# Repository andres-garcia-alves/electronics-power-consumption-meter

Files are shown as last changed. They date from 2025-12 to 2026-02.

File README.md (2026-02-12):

# Power Consumption Meter

A power consumption meter based on Arduino Nano.  
This project is a **work-in-progress**.

Two PCB versions are provided:
- Version A - With Battery Holder
- Version B - Without Battery Holder

&nbsp;

This project use the following electronic components:
- 01 x Double sided copper clad board (9x10cms)
- 01 x Arduino UNO / 01 x Arduino Nano v3
- 01 x Arduino socket (optional, 2x15)
- 01 x INA219 module
- 01 x INA219 socket (optional, 1x6)
- 01 x Display 5641BS, 7-segment, 4 digit, common anode
- 01 x Display socket (optional, 2x6)
- 11 x 470 ohm resistors
- 03 x LED diodes
- 01 x Rocker Button (optional, power on/off) / 01 x Jumper
- 01 x Switch Slide Button (power source selector)
- 01 x Switch Push Button (measure selector)
- 01 x 18650 (x2) batery holder / 01 x 9V Batery holder
- 01 x DC-jack connector (optional, externar power 5-12V)
- 01 x USB Type-A connector pair (male/female)
- 01 x USB Type-B Mini connector pair (male/female)
- 01 x USB Type-B Micro connector pair (male/female)
- 02 x DC connector-pair (male/female)
- 01 x Bornier 4-pin / 01 x JST conector 4-pin
- 04 x Bornier 2-pin / 02 x JST conector 2-pin

How to use:
- Conect this gadget between the device to measure and its power source.
- Pressing the push-button changes the measure tu display: voltage (V), consumption (mA), or total power (mW).

Features:
- Power input: 7-12V
- Measurements: 0-26V @3.2A (max)
- Accuracy: 0.01V, ~1mA, ~1mW

Notes:
- Measure only one device at a time, all power connectors intenally uses a common bus.
- Internal connections:
  - USB-A: power + data
  - USB-B mini/micro: power-only
  - DC-Jacks: power-only

&nbsp;

### Screenshots

| Breadboard | Assembly |
|---|---|
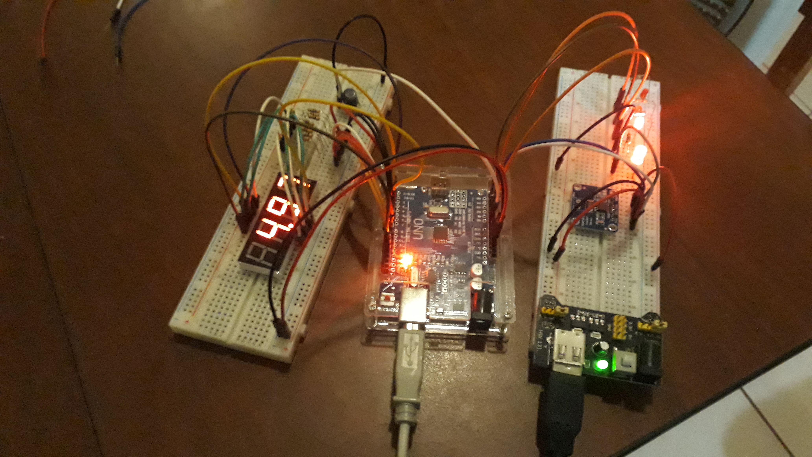
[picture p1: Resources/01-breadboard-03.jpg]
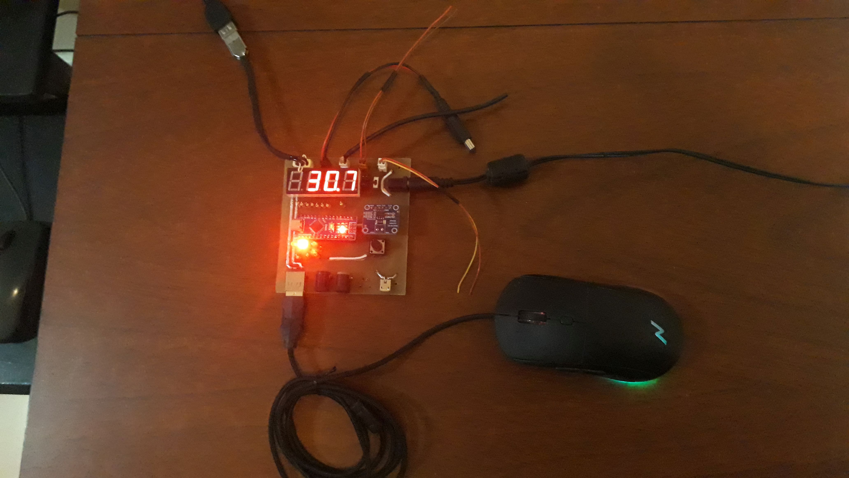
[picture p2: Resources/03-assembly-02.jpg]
|  |  |

| Version A - Schematics Diagram | Version A - PCB Diagram |
|---|---|
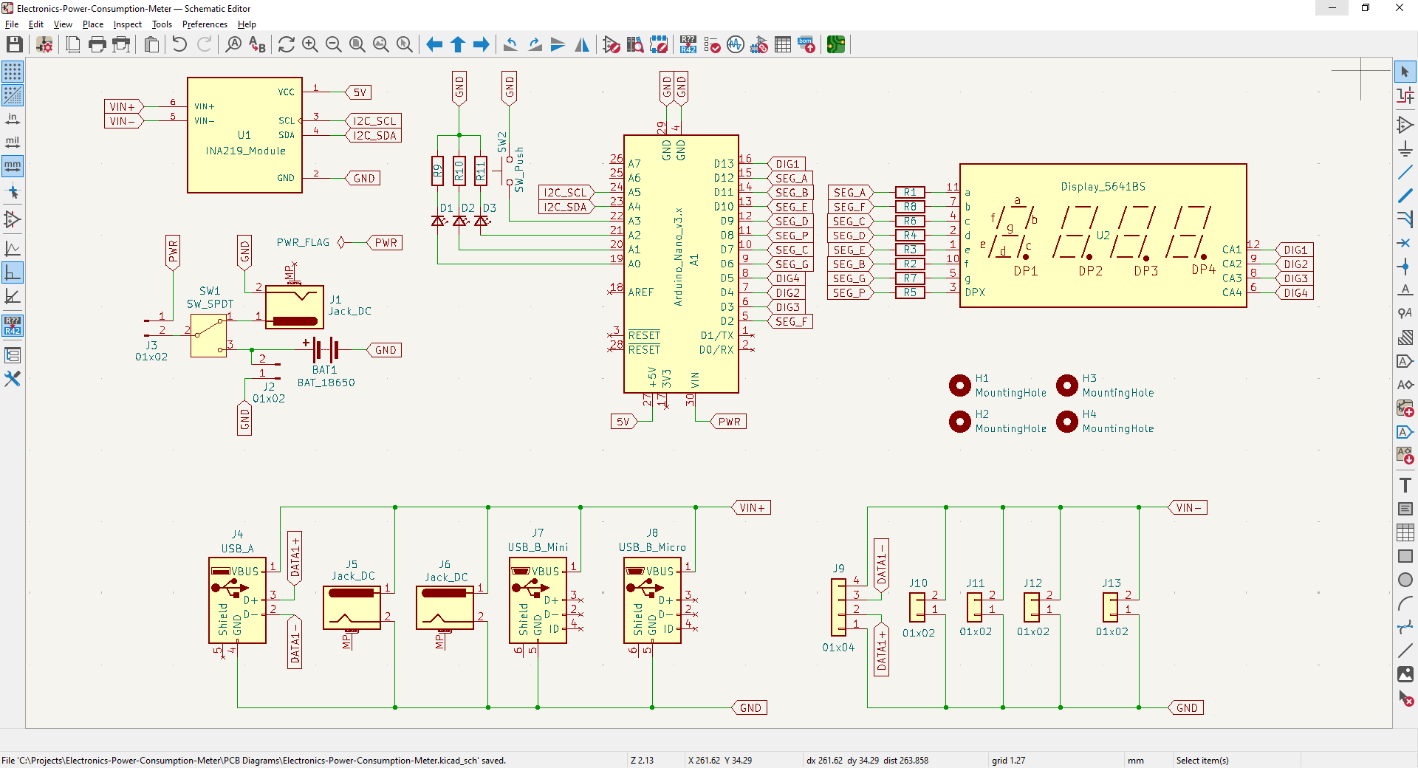
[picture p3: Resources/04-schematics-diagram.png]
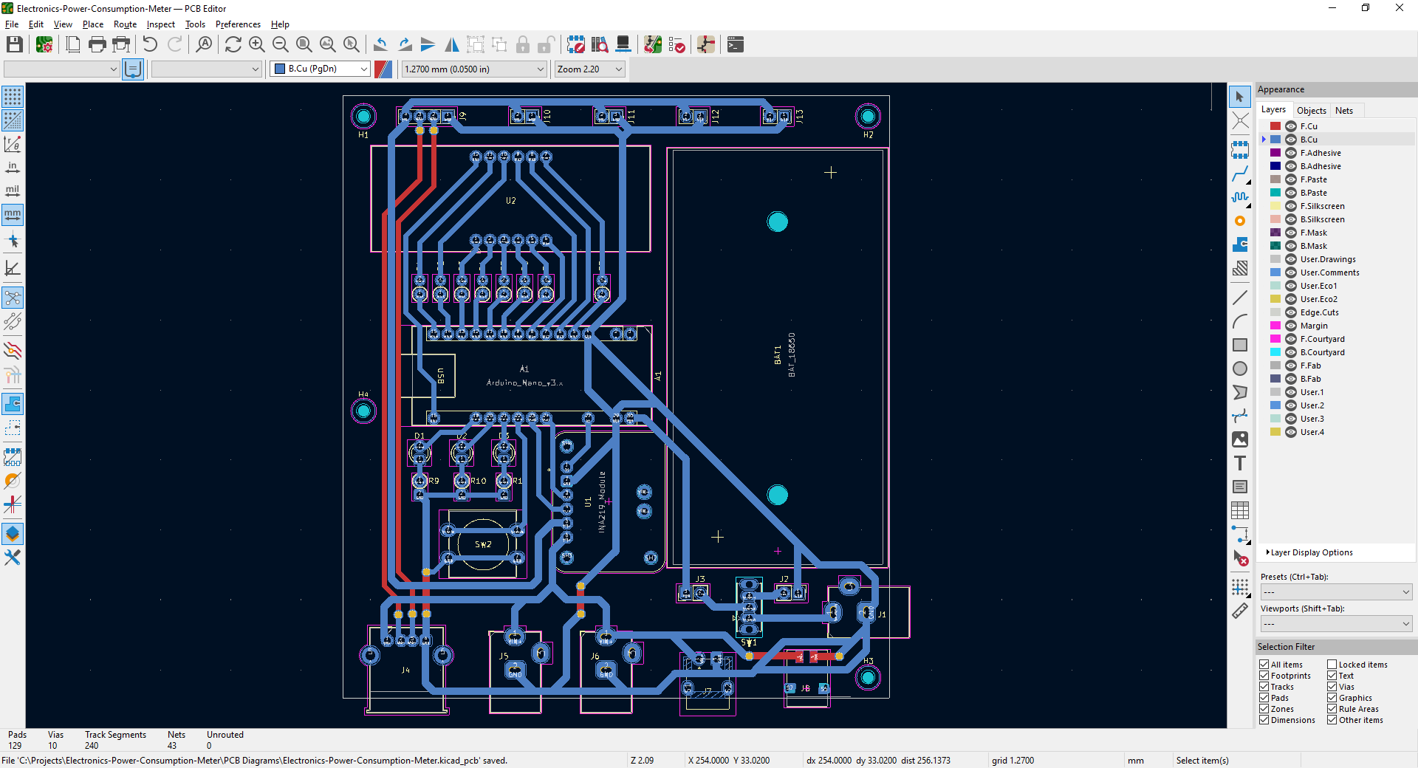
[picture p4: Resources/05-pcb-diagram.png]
|  |  |

| Version A - PCB Render 3D | Version A - PCB Render 3D |
|---|---|
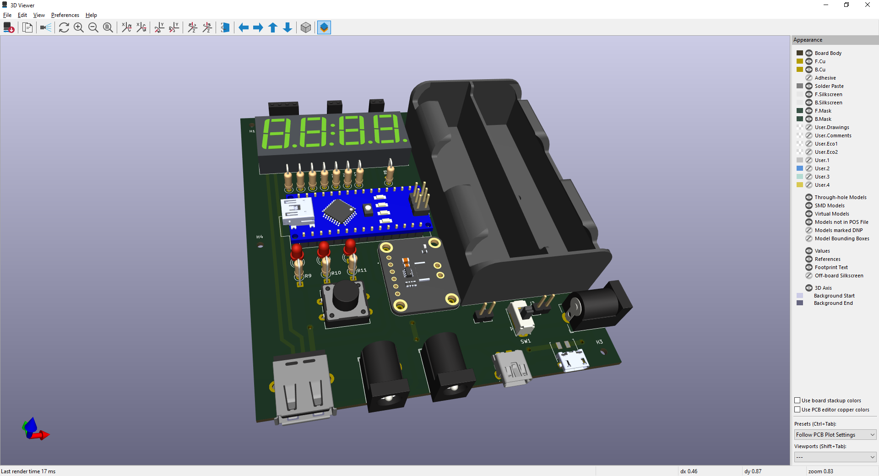
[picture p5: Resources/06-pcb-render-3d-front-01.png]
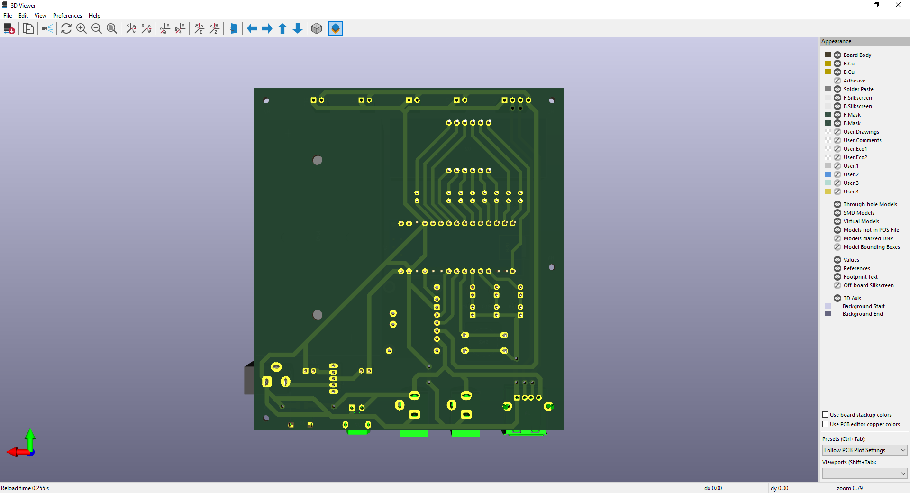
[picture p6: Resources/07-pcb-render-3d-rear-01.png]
|  |  |

| Version B - PCB Render 3D | Version B - PCB Render 3D |
|---|---|
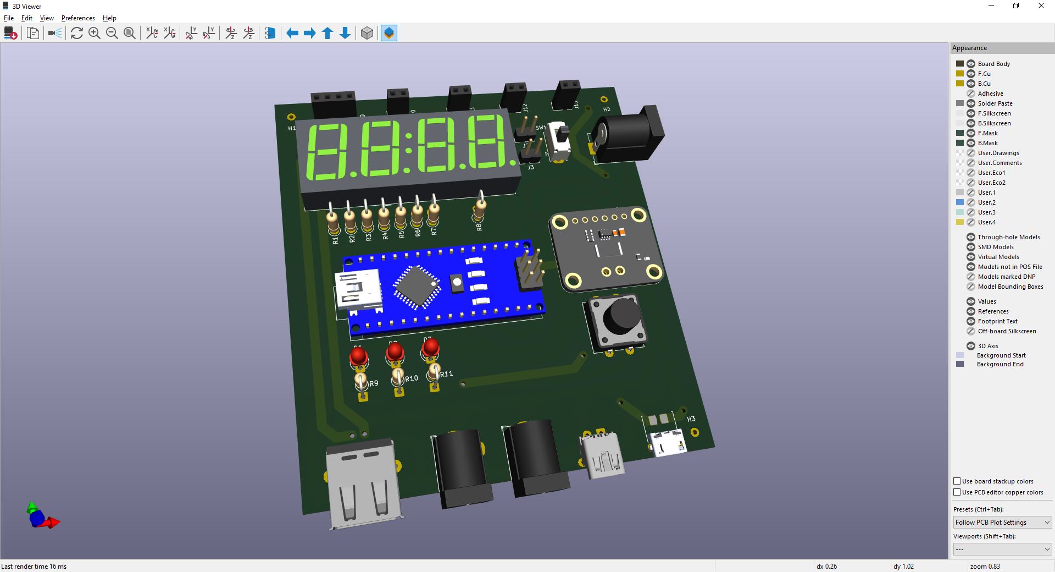
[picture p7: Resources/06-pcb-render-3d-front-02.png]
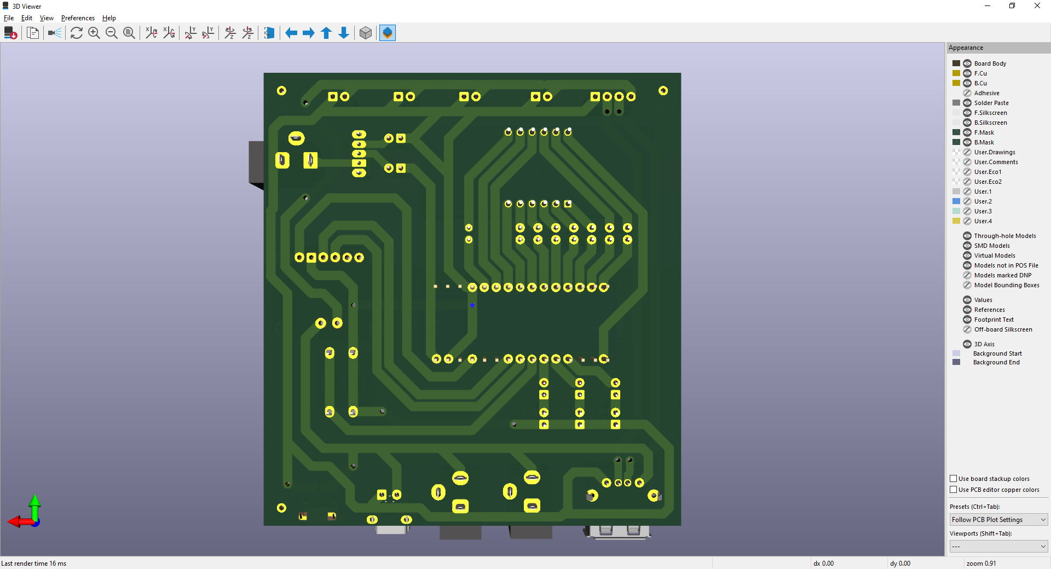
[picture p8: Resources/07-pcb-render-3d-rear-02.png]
|  |  |

| Case 3D Model | Project Final |
|---|---|
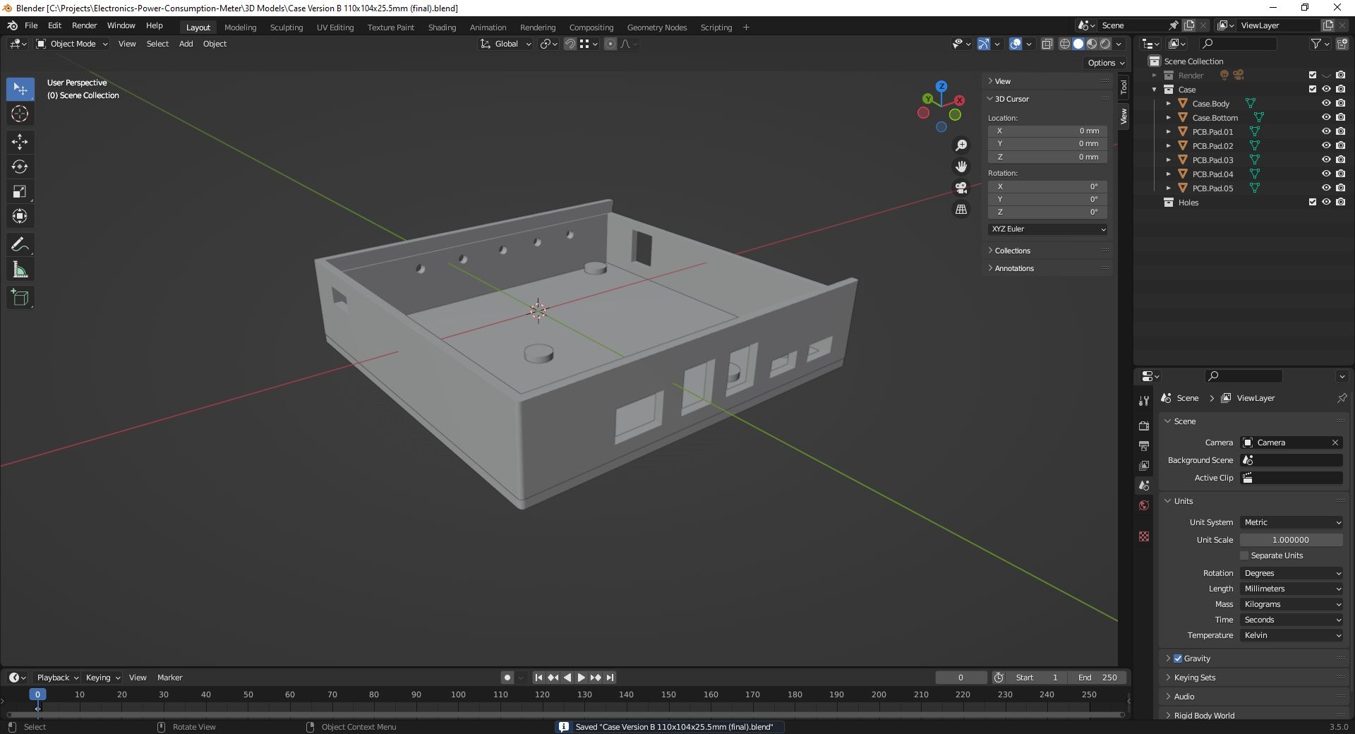
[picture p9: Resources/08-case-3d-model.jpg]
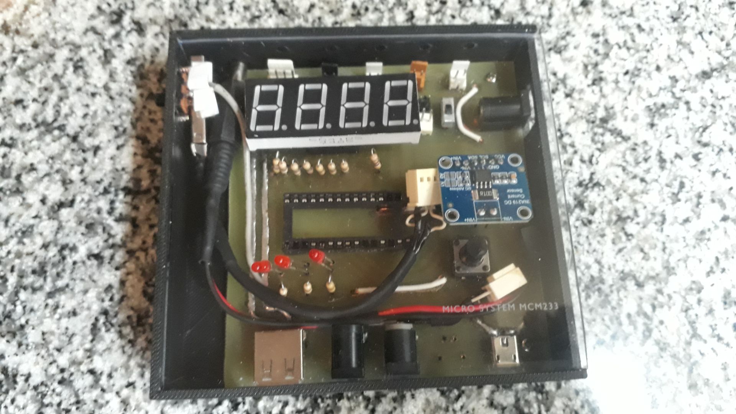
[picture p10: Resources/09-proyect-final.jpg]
|  |  |

See 'Rescources' sub-folder for more pictures & videos of the project.

&nbsp;

### Version History

v1.0 (2025.12.20) - Initial release.  
v1.1 (2025.12.21) - Version A: adding PCB schematics and layout.  
v1.2 (2025.12.22) - Version A: update PCB schematics and layout, adding firmware base code.  
v1.3 (2025.12.23) - Version A: update PCB schematics and layout, update firmware.  
v1.4 (2025.12.25) - Version B: adding PCB schematics and layout.  
v1.5 (2025.12.26) - Version A: adding case 3D model, adding 'Stickers' folder.  
v1.6 (2025.12.29) - Adding PCB building and assembly pictures.  
v1.7 (2026.01.27) - Version B: adding case 3D model.  
v1.8 (2026.02.11) - Version B: minor case 3D model improvements.  
v1.9 (2026.02.12) - Update 'README.md'.  

&nbsp;

This source code is licensed under GPL v3.0  
Please send me your feedback about this project: andres.garcia.alves@gmail.com

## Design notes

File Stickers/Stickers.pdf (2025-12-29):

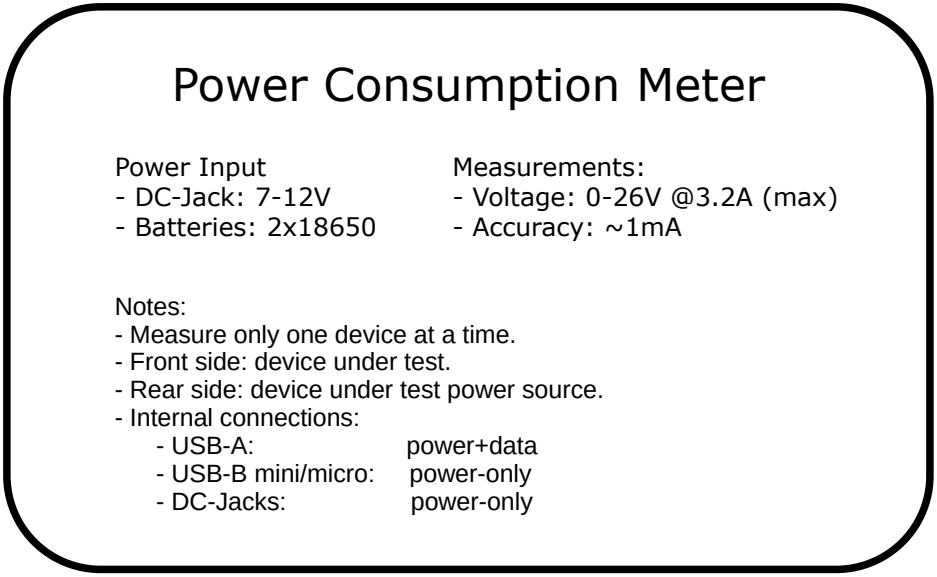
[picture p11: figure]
Power Consumption Meter; Notes: - Measure only one device at a time. - Front side: device under test.; - Internal connections:; - USB-A:; power+data; - USB-B mini/micro:; power-only; - DC-Jacks:; Power Input - DC-Jack: 7-12V - Batteries: 2x18650; Measurements: - Voltage: 0-26V @3.2A (max) - Accuracy: ~1mA

- Rear side: device under test power source.

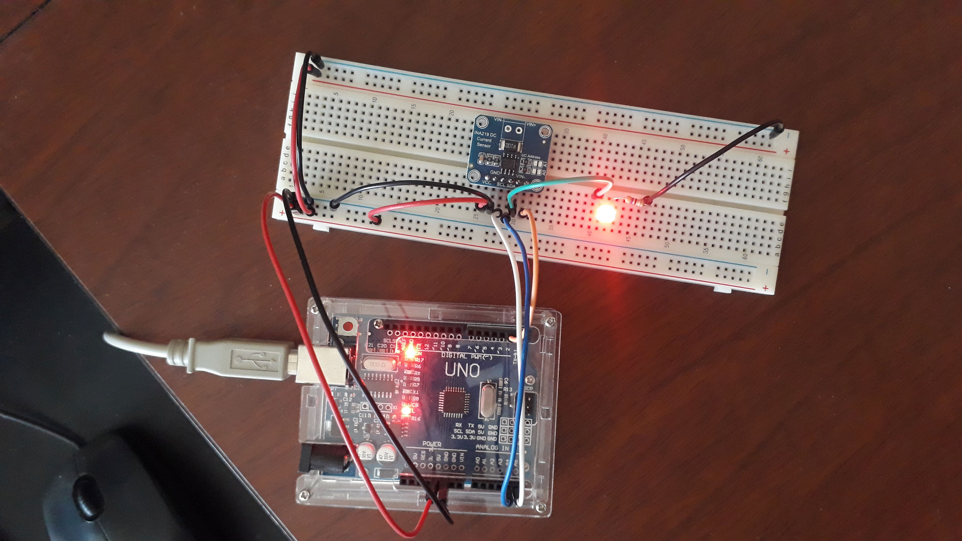
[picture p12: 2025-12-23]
Resources/01-breadboard-01.jpg

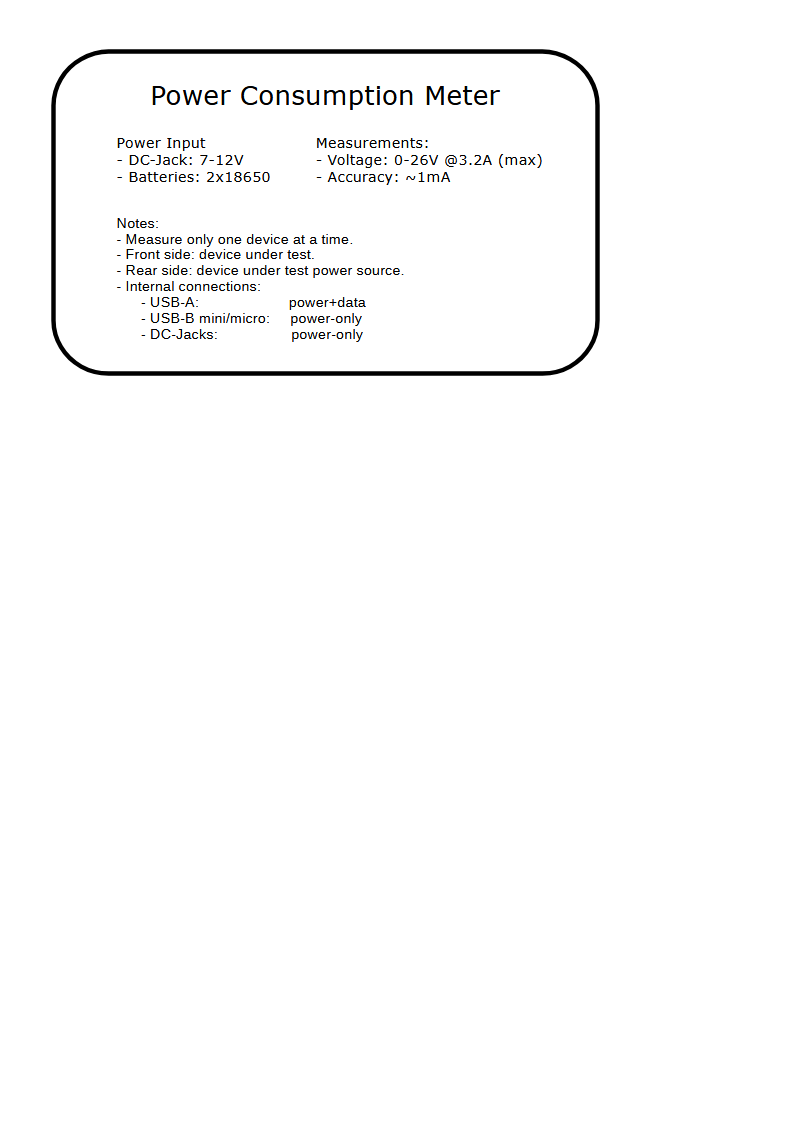
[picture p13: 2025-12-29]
Stickers/Stickers.png

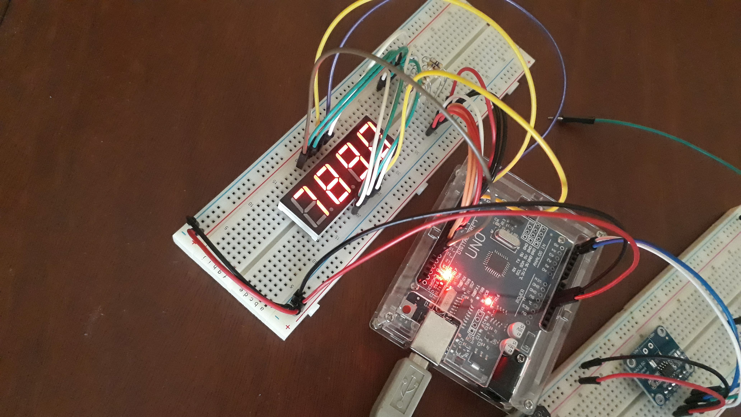
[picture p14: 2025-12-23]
Resources/01-breadboard-02.jpg

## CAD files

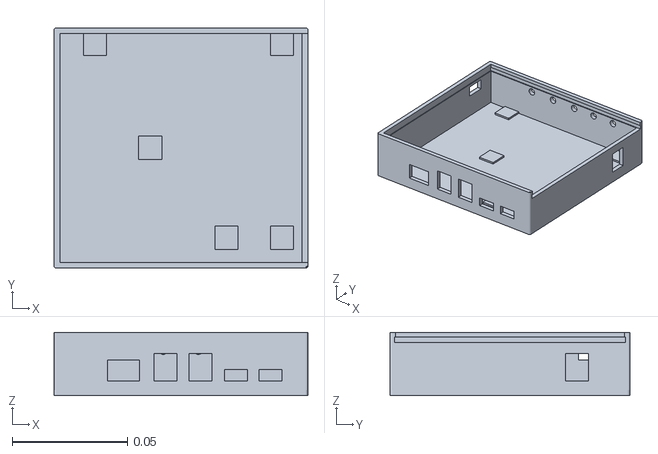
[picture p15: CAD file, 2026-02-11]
3D Models/Case Version B 110x104x27.5mm (final).stl
0.11 x 0.104 x 0.0275

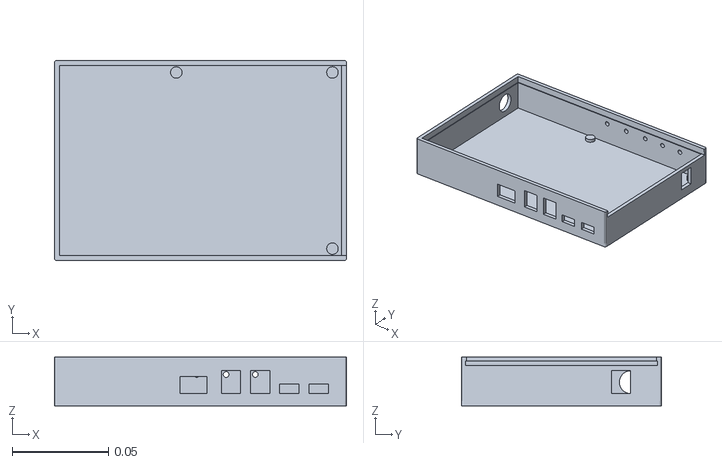
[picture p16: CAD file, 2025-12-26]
3D Models/Case Version A 152x104x25.5mm (final).stl
0.152 x 0.104 x 0.0255

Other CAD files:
3D Models/Case Version A 152x104x25.5mm (final).blend
3D Models/Case Version A 152x104x25.5mm (without holes).blend
3D Models/Case Version B 110x104x27.5mm (final).blend
3D Models/Case Version B 110x104x27.5mm (without holes).blend

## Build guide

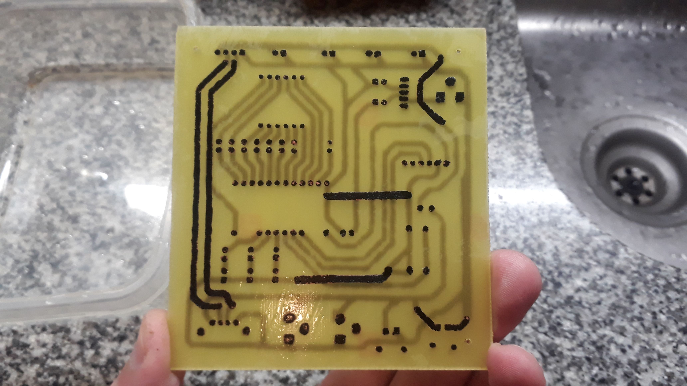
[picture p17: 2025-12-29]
Resources/02-building-pcb-05.jpg

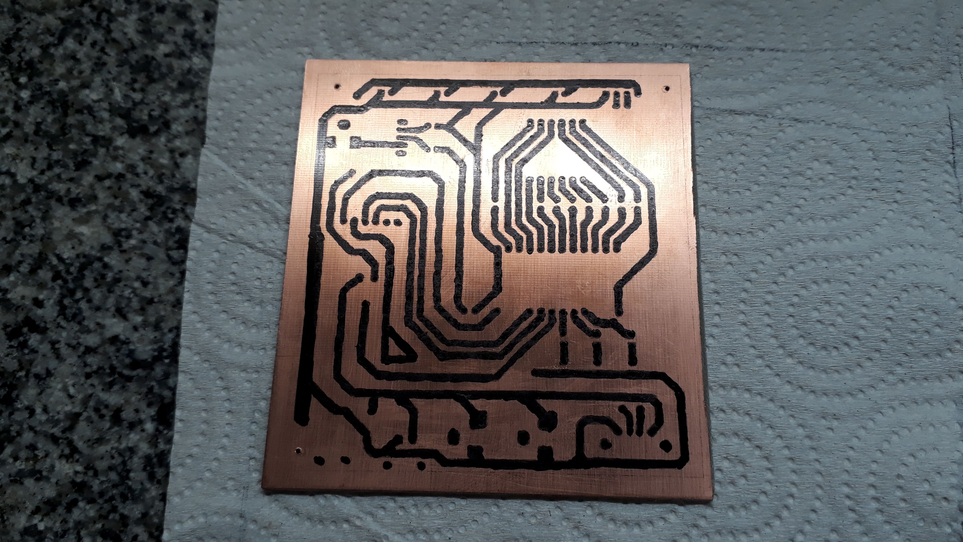
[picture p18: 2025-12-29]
Resources/02-building-pcb-03.jpg

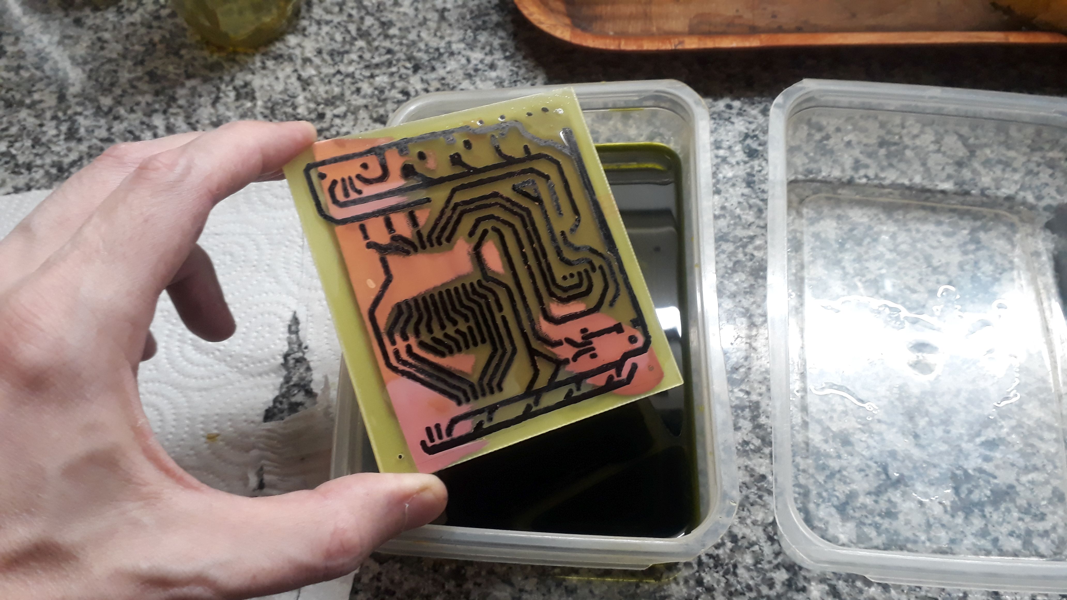
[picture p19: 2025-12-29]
Resources/02-building-pcb-04.jpg

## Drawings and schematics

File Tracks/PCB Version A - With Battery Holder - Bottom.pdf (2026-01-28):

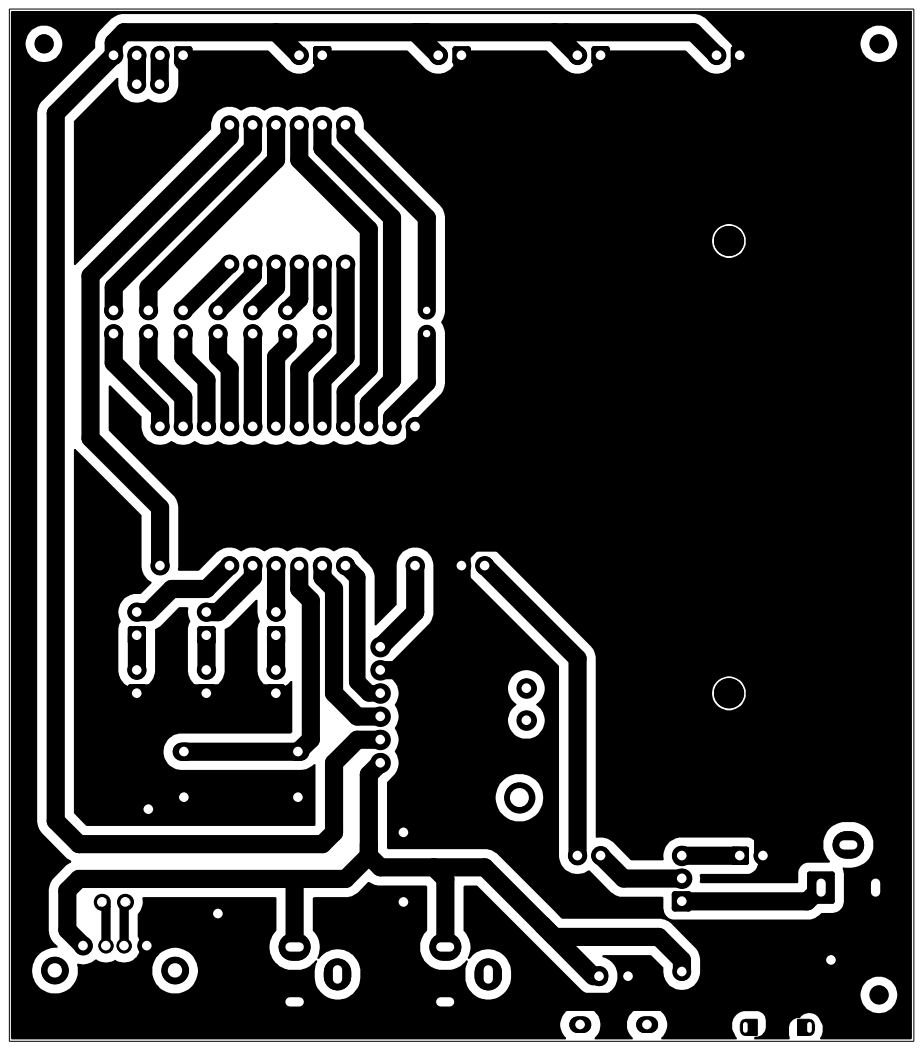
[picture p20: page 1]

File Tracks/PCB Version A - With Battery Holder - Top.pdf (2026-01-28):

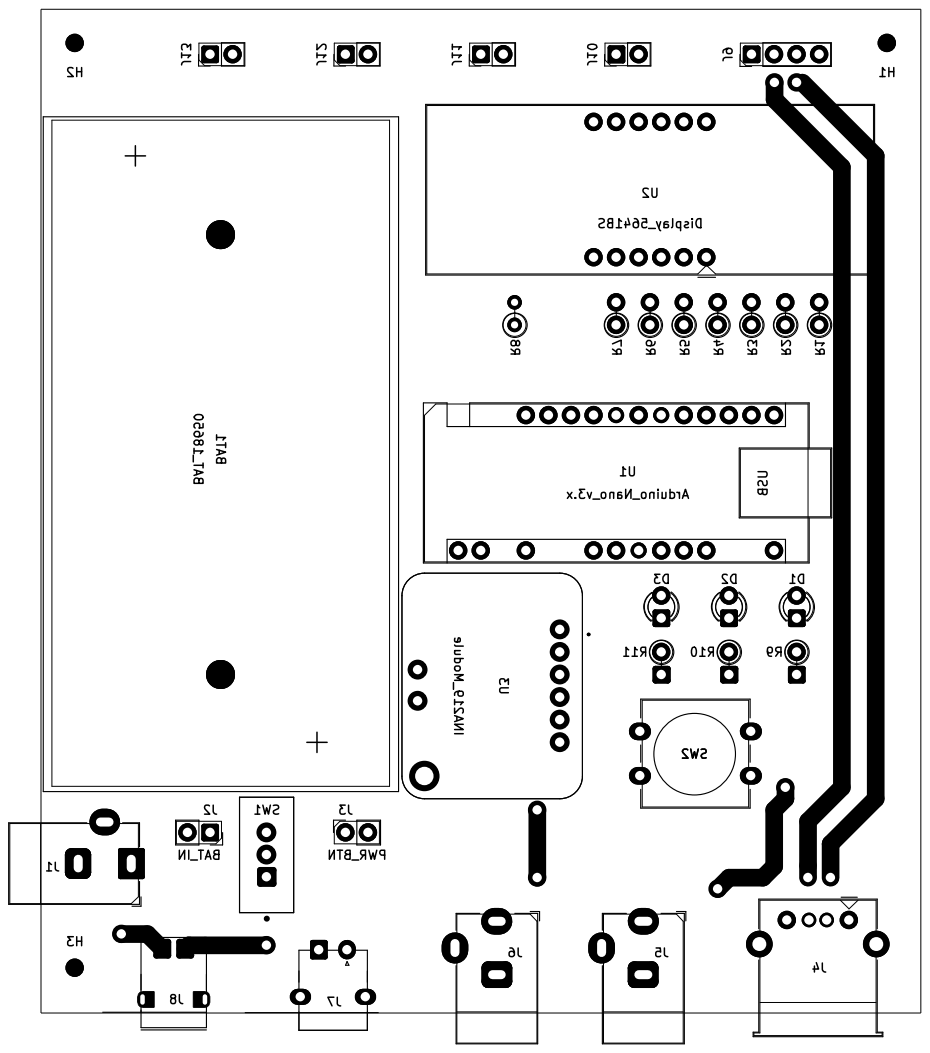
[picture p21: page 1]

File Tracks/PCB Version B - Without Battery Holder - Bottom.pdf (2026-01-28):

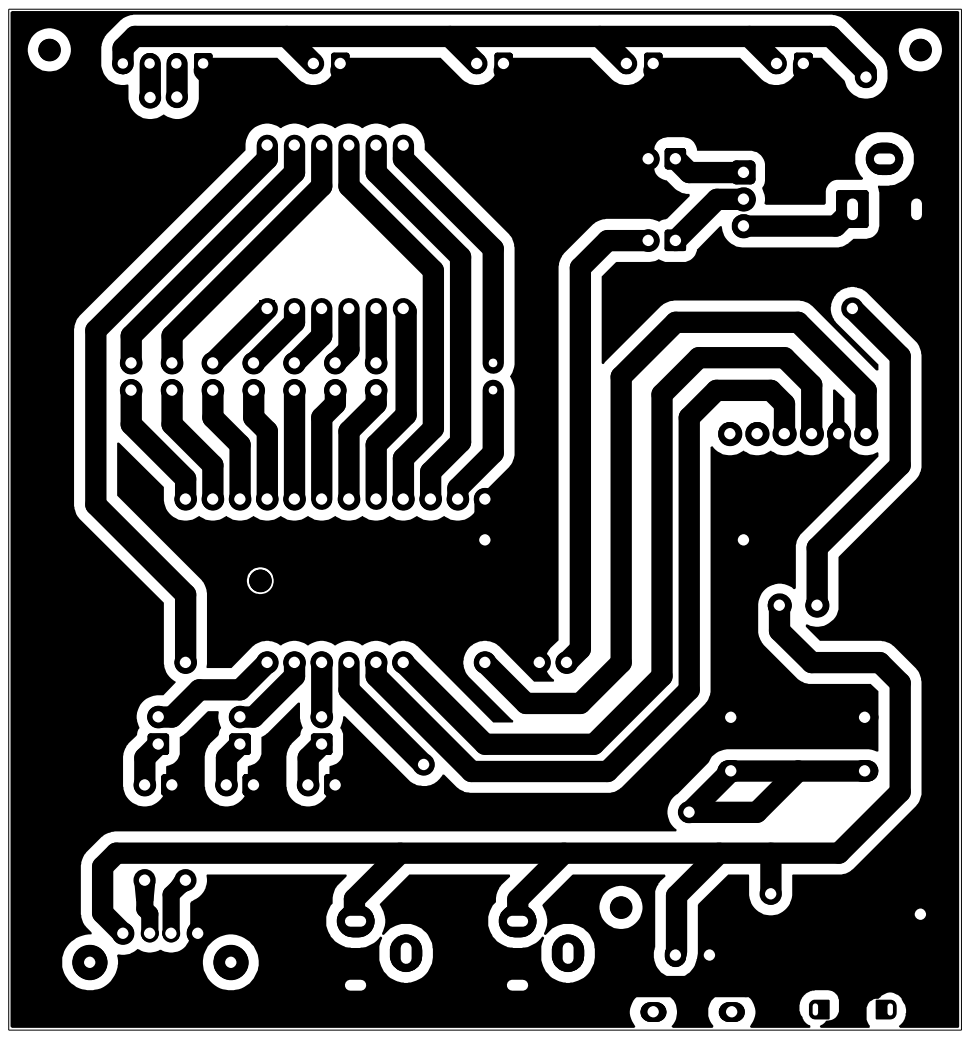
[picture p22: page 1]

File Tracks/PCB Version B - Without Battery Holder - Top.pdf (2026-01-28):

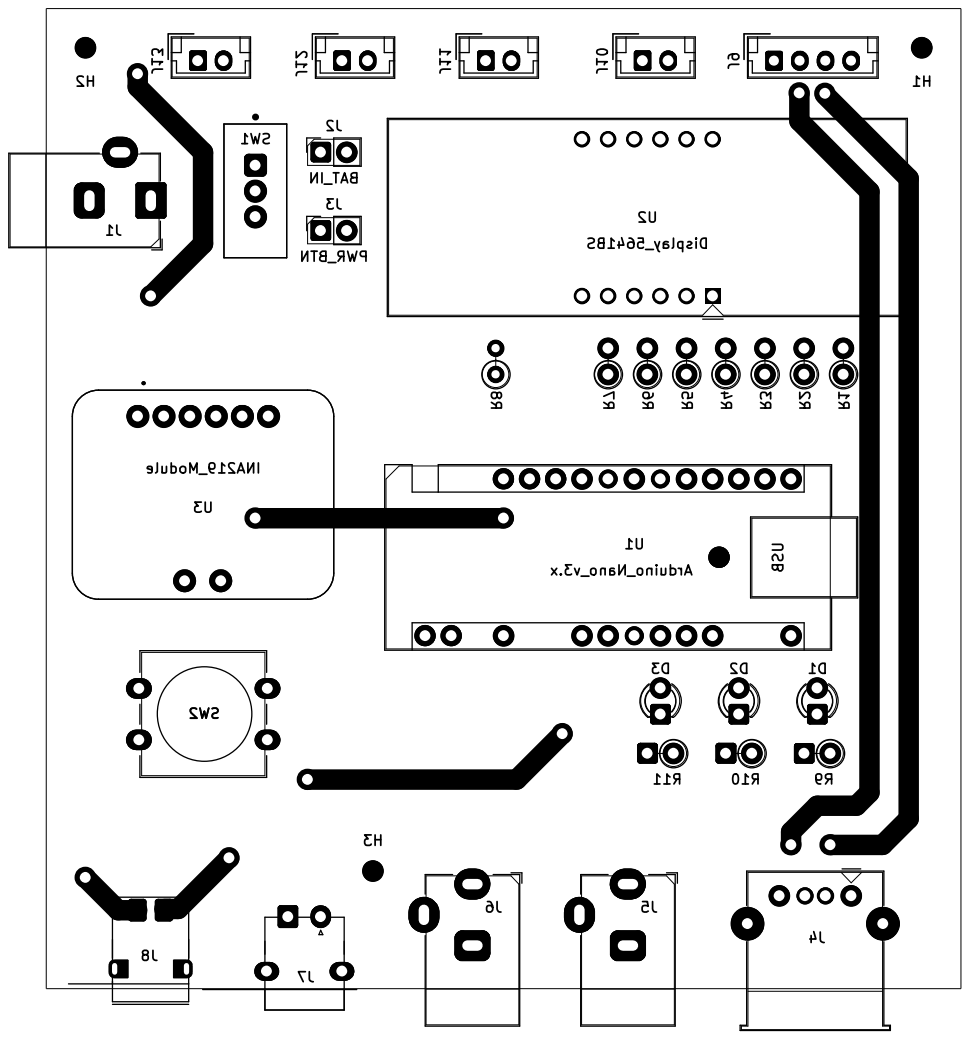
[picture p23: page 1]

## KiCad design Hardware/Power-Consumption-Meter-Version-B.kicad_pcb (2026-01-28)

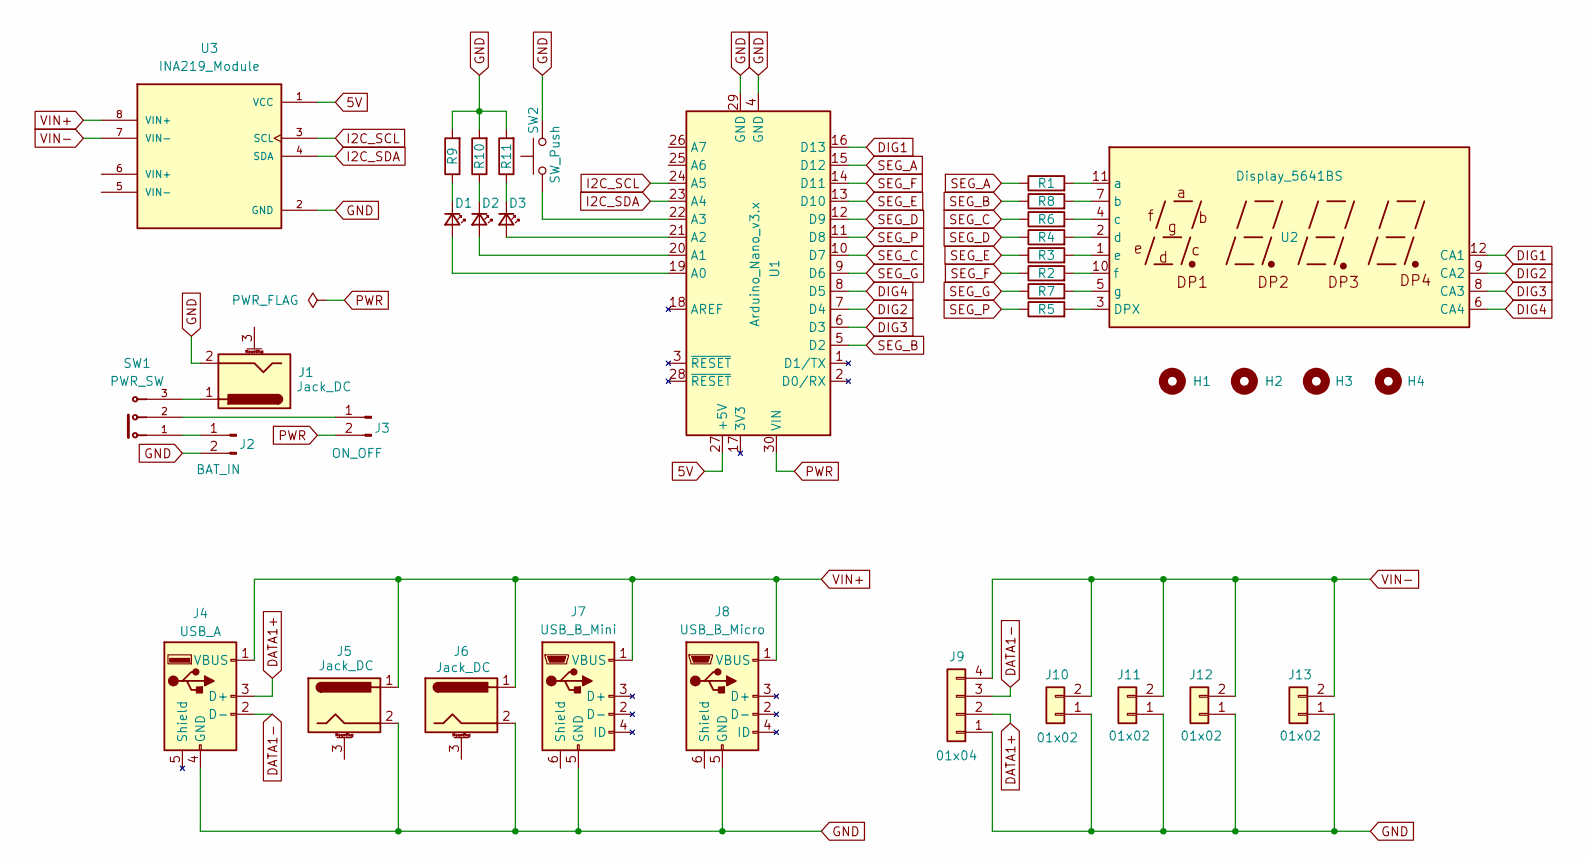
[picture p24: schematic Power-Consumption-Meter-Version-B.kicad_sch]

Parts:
D1, D2, D3: LED; LED_D3.0mm
H1, H2, H3, H4: MountingHole; MountingHole_2mm
J1, J5, J6: Jack_DC; BarrelJack_Horizontal
J2: BAT_IN; PinHeader_1x02_P2.54mm_Vertical
J3: ON_OFF; PinHeader_1x02_P2.54mm_Vertical
J4: USB_A; USB_A_Molex_67643_Horizontal
J7: USB_B_Mini; USB_B_Mini_OTG_THT_Molex_548190519
J8: USB_B_Micro; USB_B_Micro_THT_Amphenol_101181940011LF
J9: 01x04; JST_EH_B4B-EH-A_1x04_P2.50mm_Vertical
J10, J11, J12, J13: 01x02; JST_EH_B2B-EH-A_1x02_P2.50mm_Vertical
R1, R2, R3, R4, R5, R6, R7, R8, R9, R10, R11: R470; R_Axial_DIN0207_L6.3mm_D2.5mm_P2.54mm_Vertical
SW1: PWR_SW; Switch_Slide_SPDT_Straight_TE_1825159_1
SW2: SW_Push; SW_PUSH-12mm_Wuerth-430476085716
U1: Arduino_Nano_v3.x; Arduino_Nano_v3
U2: Display_5641BS; CA56-12CGKWA
U3: INA219_Module; INA219_Module_Generic

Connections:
5V: U1.27 (+5V), U3.1 (VCC)
DATA1+: J4.3 (D+), J9.2
DATA1-: J4.2 (D-), J9.3
DIG1: U1.16 (D13), U2.12 (CA1)
DIG2: U1.7 (D4), U2.9 (CA2)
DIG3: U1.6 (D3), U2.8 (CA3)
DIG4: U1.8 (D5), U2.6 (CA4)
GND: J1.2, J2.2, J4.4 (GND), J5.2, J6.2, J7.5 (GND), J8.5 (GND), J9.1, J10.1, J11.1, J12.1, J13.1, R9.2, R10.2, R11.2, SW2.2, U1.4 (GND), U1.29 (GND), U3.2 (GND)
I2C_SCL: U1.24 (A5), U3.3 (SCL)
I2C_SDA: U1.23 (A4), U3.4 (SDA)
unnamed: D1.2 (A), U1.19 (A0)
unnamed: D1.1 (K), R9.1
unnamed: D2.2 (A), U1.20 (A1)
unnamed: D2.1 (K), R10.1
unnamed: D3.2 (A), U1.21 (A2)
unnamed: D3.1 (K), R11.1
unnamed: J1.1, SW1.3
unnamed: J2.1, SW1.1
unnamed: J3.1, SW1.2
unnamed: SW2.1, U1.22 (A3)
unnamed: R5.2, U2.3 (DPX)
unnamed: R1.2, U2.11 (a)
unnamed: R8.2, U2.7 (b)
unnamed: R6.2, U2.4 (c)
unnamed: R4.2, U2.2 (d)
unnamed: R3.2, U2.1 (e)
unnamed: R2.2, U2.10 (f)
unnamed: R7.2, U2.5 (g)
PWR: J3.2, U1.30 (VIN)
SEG_A: R1.1, U1.15 (D12)
SEG_B: R8.1, U1.5 (D2)
SEG_C: R6.1, U1.10 (D7)
SEG_D: R4.1, U1.12 (D9)
SEG_E: R3.1, U1.13 (D10)
SEG_F: R2.1, U1.14 (D11)
SEG_G: R7.1, U1.9 (D6)
SEG_P: R5.1, U1.11 (D8)
VIN+: J4.1 (VBUS), J5.1, J6.1, J7.1 (VBUS), J8.1 (VBUS), U3.8 (VIN+)
VIN-: J9.4, J10.2, J11.2, J12.2, J13.2, U3.7 (VIN-)

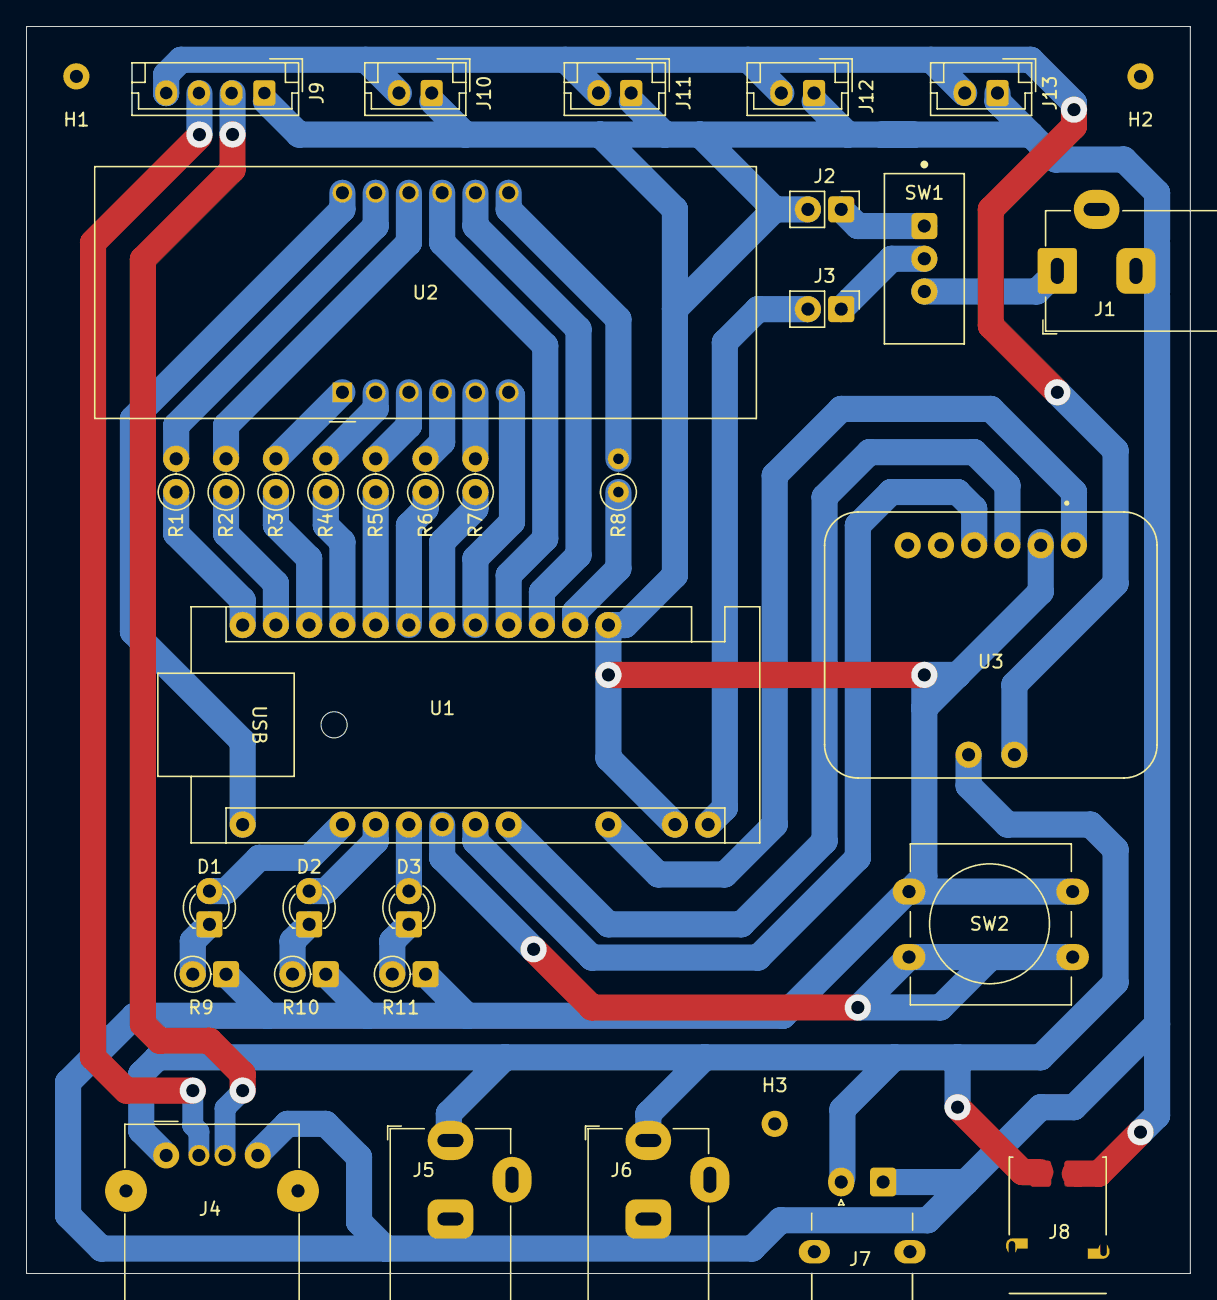
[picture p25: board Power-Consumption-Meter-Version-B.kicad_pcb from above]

Board: 2 copper layers, 88.9 x 95.2 mm, 36 parts (0 on the bottom side), 39 nets.

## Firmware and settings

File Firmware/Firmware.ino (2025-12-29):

#include "definitions.h"
#include "debug.h"
#include "display.h"
#include "input.h"
#include "measurements.h"

void setup(void) 
{
  debugInit();
  displayInit();
  measureInit();
  inputInit();
}

void loop(void)
{
  processInput();

  RawData rawData = measureGetRawData();
  processData(rawData);
}


void processData(RawData rawData)
{
  if (!rawData.isValid) { displayInvalid(); return; }

  // ignore the direction of the electric current
  rawData.current = abs(rawData.current);

  // correct spurious reading under no-load conditions
  if (rawData.current < SPURIOUS_THRESHOLD) { // < 0.5 mA
    rawData.loadVoltage = 0.0;
    rawData.current = 0.0;
    rawData.power = 0.0;
  }

  // display que correct value
  WorkingMode workingMode = getWorkingMode();
  if (workingMode == VOLTAGE)       { displayNumber(rawData.loadVoltage, 2); }
  else if (workingMode == CURRENT)  { displayNumber(rawData.current, 1); }
  else if (workingMode == POWER)    { displayNumber(rawData.power, 1); }
  else                              { displayBlank(); }
}

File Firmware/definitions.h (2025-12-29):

#ifndef DEFINITIONS_H
#define DEFINITIONS_H

// display: digit selector pins
#define DISPLAY_DIGIT_1     13
#define DISPLAY_DIGIT_2     4
#define DISPLAY_DIGIT_3     3
#define DISPLAY_DIGIT_4     5

// display: segment pins
#define DISPLAY_SEG_A       12
#define DISPLAY_SEG_B       2
#define DISPLAY_SEG_C       7
#define DISPLAY_SEG_D       9
#define DISPLAY_SEG_E       10
#define DISPLAY_SEG_F       11
#define DISPLAY_SEG_G       6
#define DISPLAY_SEG_DOT     8

// sensor INA219
#define I2C_SCL             A5
#define I2C_SDA             A4

// other hardware
#define LED_VOLTAGE         A0
#define LED_CURRENT         A1
#define LED_POWER           A2
#define PUSH_BTN            A3

// miscellaneous
#define DEBOUNCE_TIME       50
#define SPURIOUS_THRESHOLD  0.5

// enumerations
enum WorkingMode { VOLTAGE, CURRENT, POWER };

// data structures
struct RawData
{
  bool isValid = false;
  float busVoltage = 0;
  float shuntVoltage = 0;
  float loadVoltage = 0;
  float current = 0;
  float power = 0;
};

#endif

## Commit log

2025-12-22 adding schematics and PCB
    [Electronics-Power-Consumption-Meter.kicad_pcb, Electronics-Power-Consumption-Meter.kicad_sch]
2025-12-23 update schematics+pcb, add firmware code
    [Electronics-Power-Consumption-Meter.kicad_pcb, Electronics-Power-Consumption-Meter.kicad_sch]
2025-12-23 update firmware
    [Electronics-Power-Consumption-Meter.kicad_pcb, Electronics-Power-Consumption-Meter.kicad_sch]
2025-12-23 update schematics and PCB
    [Electronics-Power-Consumption-Meter.kicad_pcb, Electronics-Power-Consumption-Meter.kicad_sch]
2025-12-25 Adding PCB version 2 without baterry holder
    [Electronics-Power-Consumption-Meter.kicad_pcb, Electronics-Power-Consumption-Meter.kicad_sch]
2025-12-26 Adding case 3D model
    [Case 152x104x26mm (final).blend, Case 152x104x26mm (final).stl, Case 152x104x26mm (without holes).blend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]
2025-12-26 Adding case 3D model, adding 'Stickers' folder
    [Power-Consumption-Meter.kicad_pcb, Power-Consumption-Meter.kicad_sch]
2025-12-29 update PCB connectors
    [Power-Consumption-Meter.kicad_pcb, Power-Consumption-Meter.kicad_sch]
2025-12-29 Adding PCB building and assembly pictures
    [Power-Consumption-Meter.kicad_pcb, Power-Consumption-Meter.kicad_sch]
2026-01-28 Version B: adding case 3D model
    [Case 152x104x26mm (without holes).blend, Case Version A 152x104x25.5mm (final).blend, Case Version A 152x104x25.5mm (final).stl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]
2026-02-10 minor case 3D model improvements
    [Case Version B 110x104x25.5mm (final).blend, Case Version B 110x104x25.5mm (final).stl, Case Version B 110x104x25.5mm (without holes).blend]
2026-02-13 Update 'README.md'
    [Case Version B 110x104x27.5mm (final).blend, Case Version B 110x104x27.5mm (final).stl, Case Version B 110x104x27.5mm (without holes).blend]
